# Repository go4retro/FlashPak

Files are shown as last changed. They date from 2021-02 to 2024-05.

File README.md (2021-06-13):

# FlashPak - 512kB FLASH ROM Cartridge Unit for the TANDY Color Computer 1, 2, 3, and Dragon

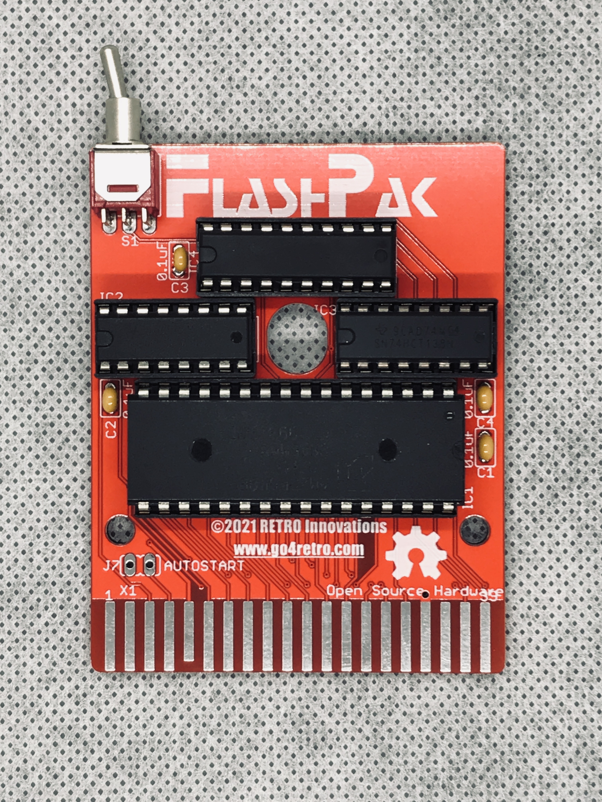
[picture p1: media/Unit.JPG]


This cartridge supports 512kB of system programmable FLASH ROM utilizing the RoboCop (Zumwalt) banking system.

## Technical Details
Banks are 16kB in size (technically, 16KiB - 256 bytes, since $ff00-$ffff is reserved for IO and vectors), which allows operation on all TANDY Color Computer models and the Dragon Data Dragon machines.  FLASH ROM appears at location $c000 in the memory map, while the banking register appears at $ff40.  The bits in the banking register are as follows:

| IO Location | Bit Location | Description |
| --- | --- | --- |
| $ff40 | 4:0 | FLASH address lines A18-A14 |
| | 7 | 1 = Programming Enabled |

The system is designed to utilize AM29F040B FLASH ROMs, but can also accommodate 16kB-512kB FLASH ROMs or EPROMs via J1-J5.  Please see schematic for more details.  If EPROMs are utilized, IC3 is not required (EPROMs cannot be system programmable)

To program please consult the AM29F040B datasheet for details, but essentially:

* set bit 7 to 1 and select bank in bank register
* via machine language, store the following values:
* store $aa in $c555
* store $55 in $c2aa
* store $a0 in $c555
* store desired value in $c000-$feff address ($fdff on Color Computer 3, I believe)

Sample stub code is available in the src/ directory.  The programming must be precise and cannot easily be performed from BASIC[1].

[1]: To simplify construction and reduce cost, programming is enabled for all of $c000-$ffff.  This includes the entire $ffxx IO region.  Unless care is taken to disable BASIC or the IRQ handlers from accessing $ffxx regions while sending the special programming sequence, the sequence will be disrupted and programming will not occur.

## Photos

Unit

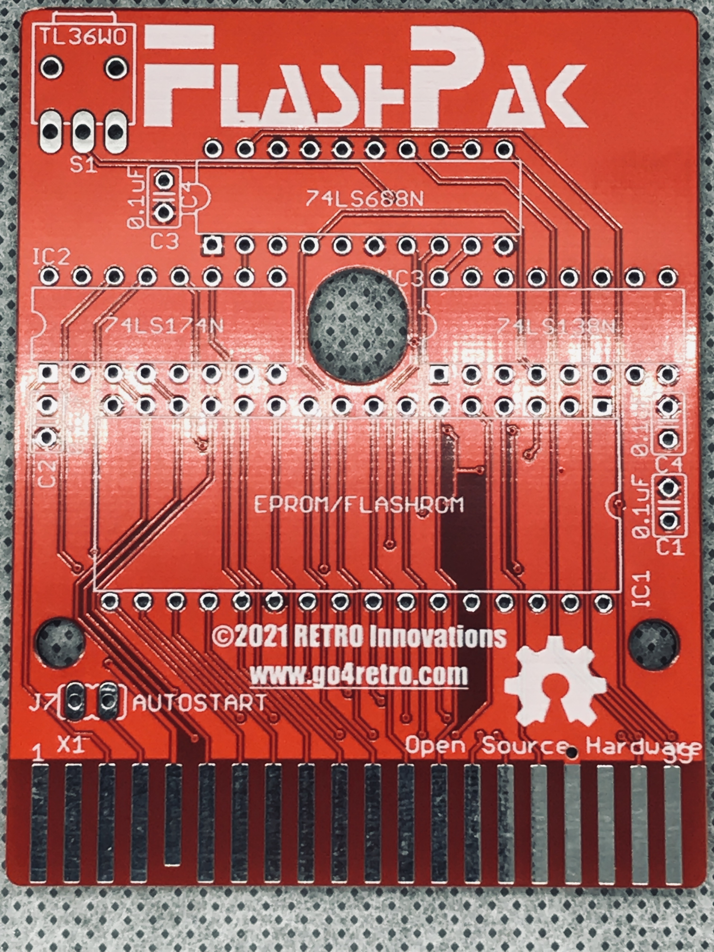
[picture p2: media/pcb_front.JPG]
pcb_front


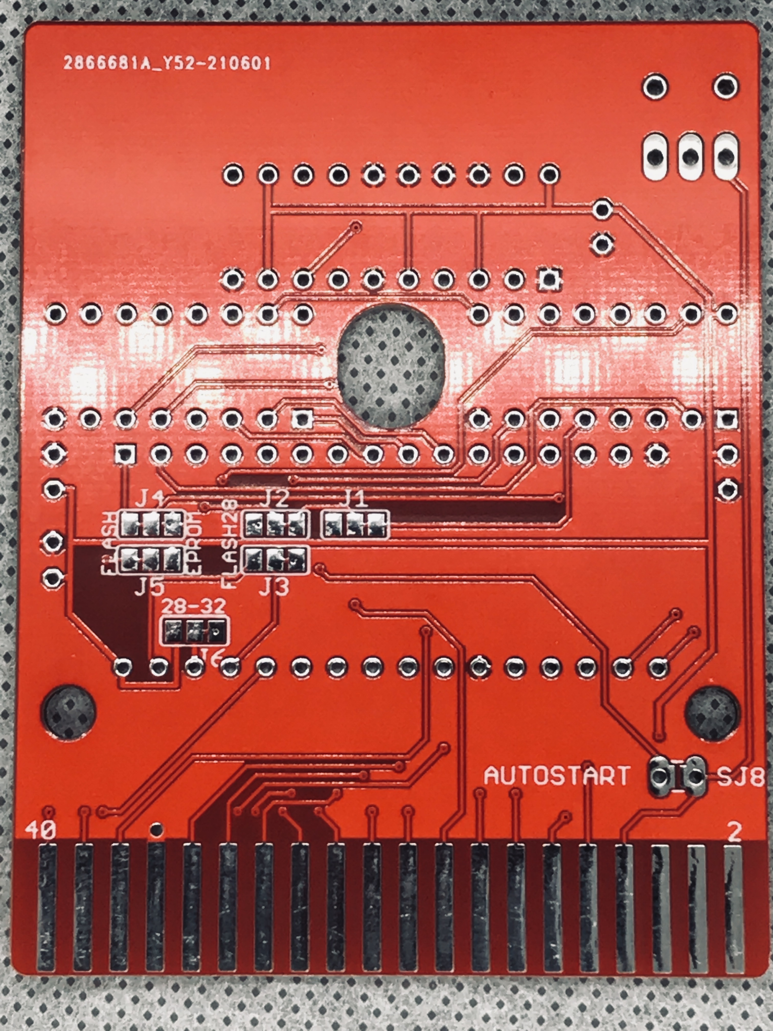
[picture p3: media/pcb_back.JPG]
pcb_back


## License
Copyright (C) 2021  RETRO Innovations

These files are free designs; you can redistribute them and/or modify
them under the terms of the Creative Commons Attribution-ShareAlike 
4.0 International License.

You should have received a copy of the license along with this
work. If not, see <http://creativecommons.org/licenses/by-sa/4.0/>.

These files are distributed in the hope that they will be useful,
but WITHOUT ANY WARRANTY; without even the implied warranty of
MERCHANTABILITY or FITNESS FOR A PARTICULAR PURPOSE.  See the
license for more details.

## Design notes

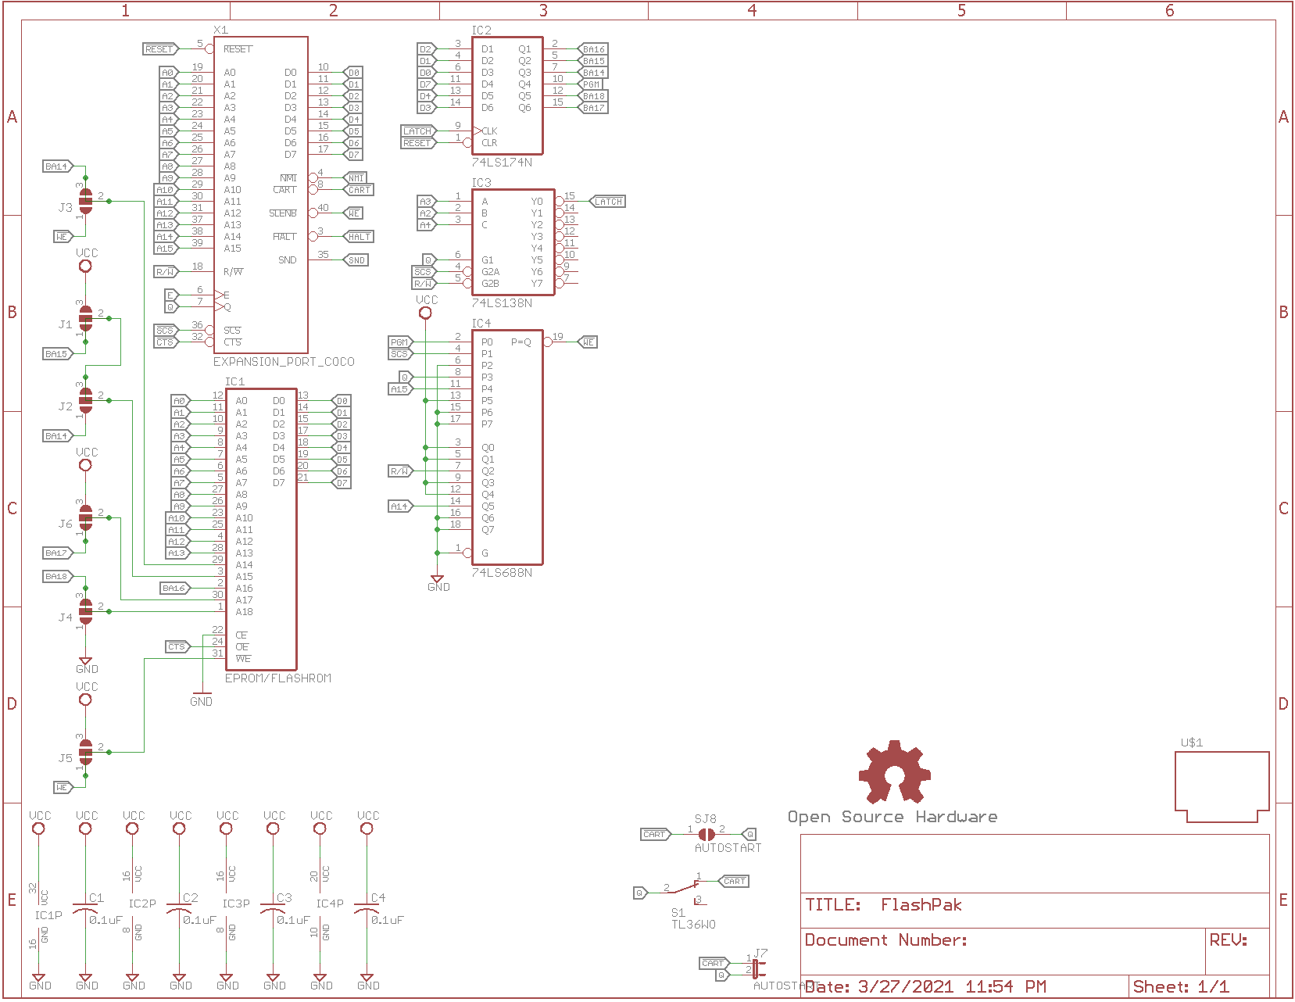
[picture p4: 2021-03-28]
pcb/FlashPak Schematic.png

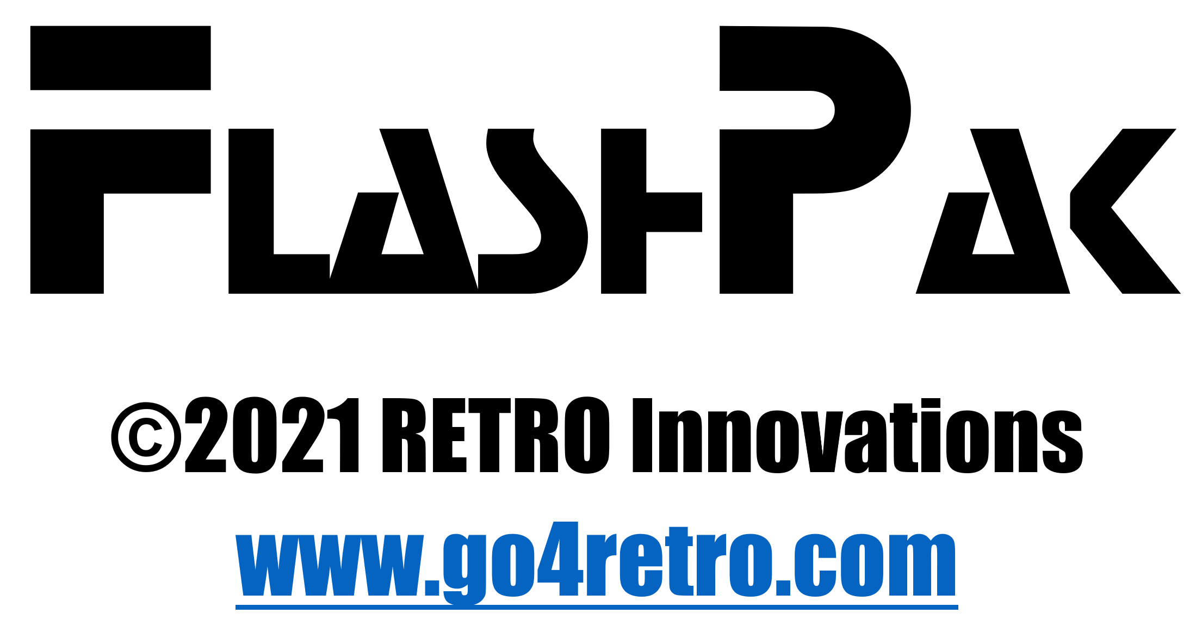
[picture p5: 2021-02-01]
doc/FlashPak Label.PNG

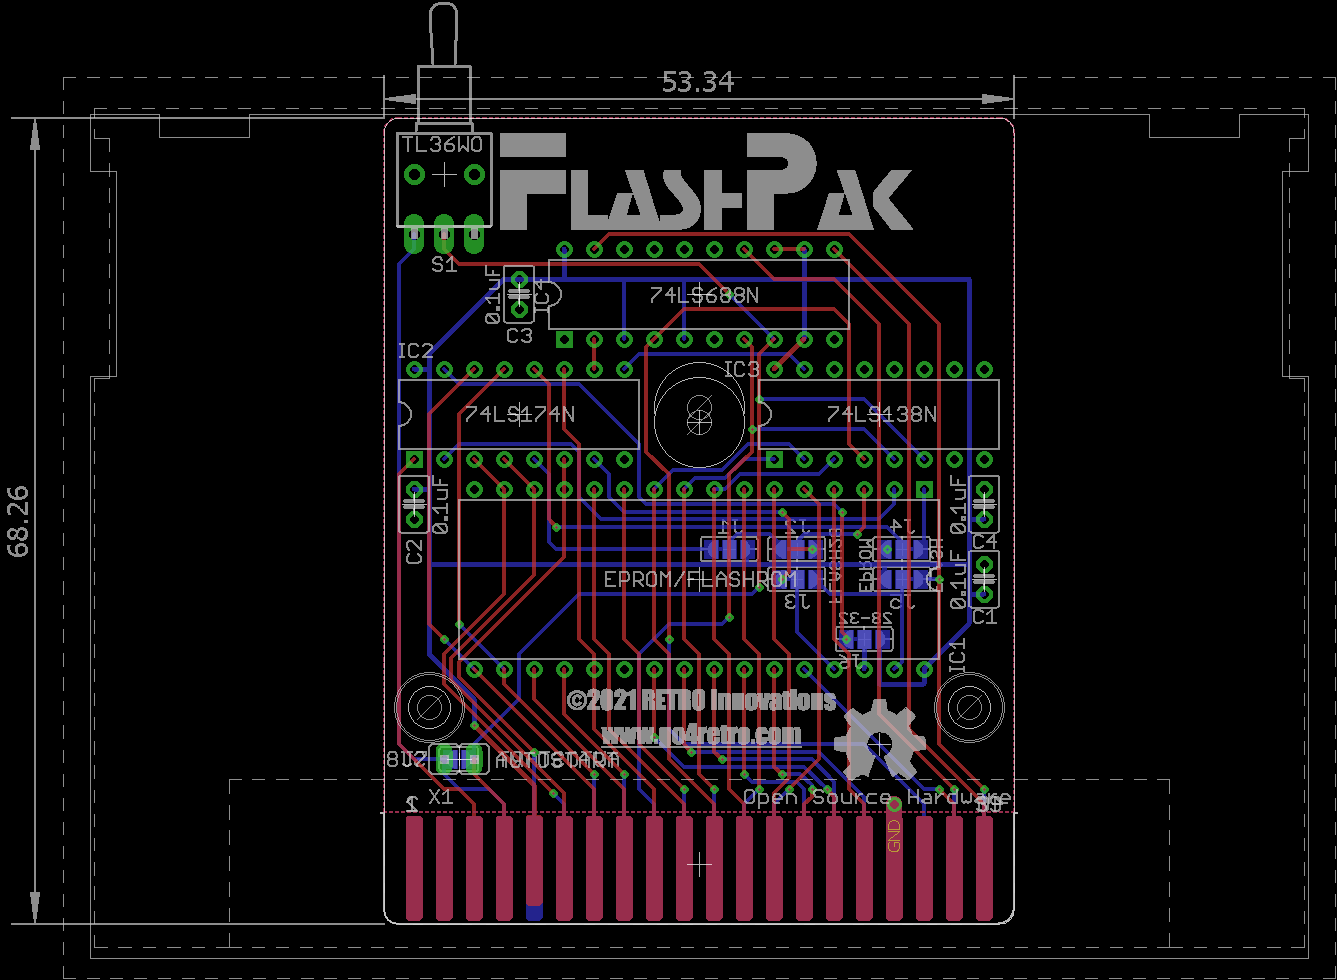
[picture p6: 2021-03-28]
pcb/FlashPak PCB.png

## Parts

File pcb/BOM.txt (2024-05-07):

Partlist

Exported from FlashPak.sch at 5/6/2024 11:41 PM

EAGLE Version 7.7.0 Copyright (c) 1988-2016 CadSoft

Assembly variant: 

Part     Value               Device              Package      Library     Sheet

C1       0.1uF               C-US025-025X050     C025-025X050 rcl         1
C2       0.1uF               C-US025-025X050     C025-025X050 rcl         1
C3       0.1uF               C-US025-025X050     C025-025X050 rcl         1
C4       0.1uF               C-US025-025X050     C025-025X050 rcl         1
IC1      EPROM/FLASHROM      SST39SF040APHR      DIL32-RP     memory-sst  1
IC2      74LS174N            74LS174N            DIL16-RP     74xx-us-jlb 1
IC3      74LS138N            74LS138N            DIL16-RP     74xx-us-jlb 1
IC4      74LS688N            74LS688N            DIL20-RP     74xx-us-jlb 1
S1       TL36WO              TL36WO              TL3XWO       switch      1
SJ8      AUTOSTART           SJ                  SJ           jumper-jlb  1

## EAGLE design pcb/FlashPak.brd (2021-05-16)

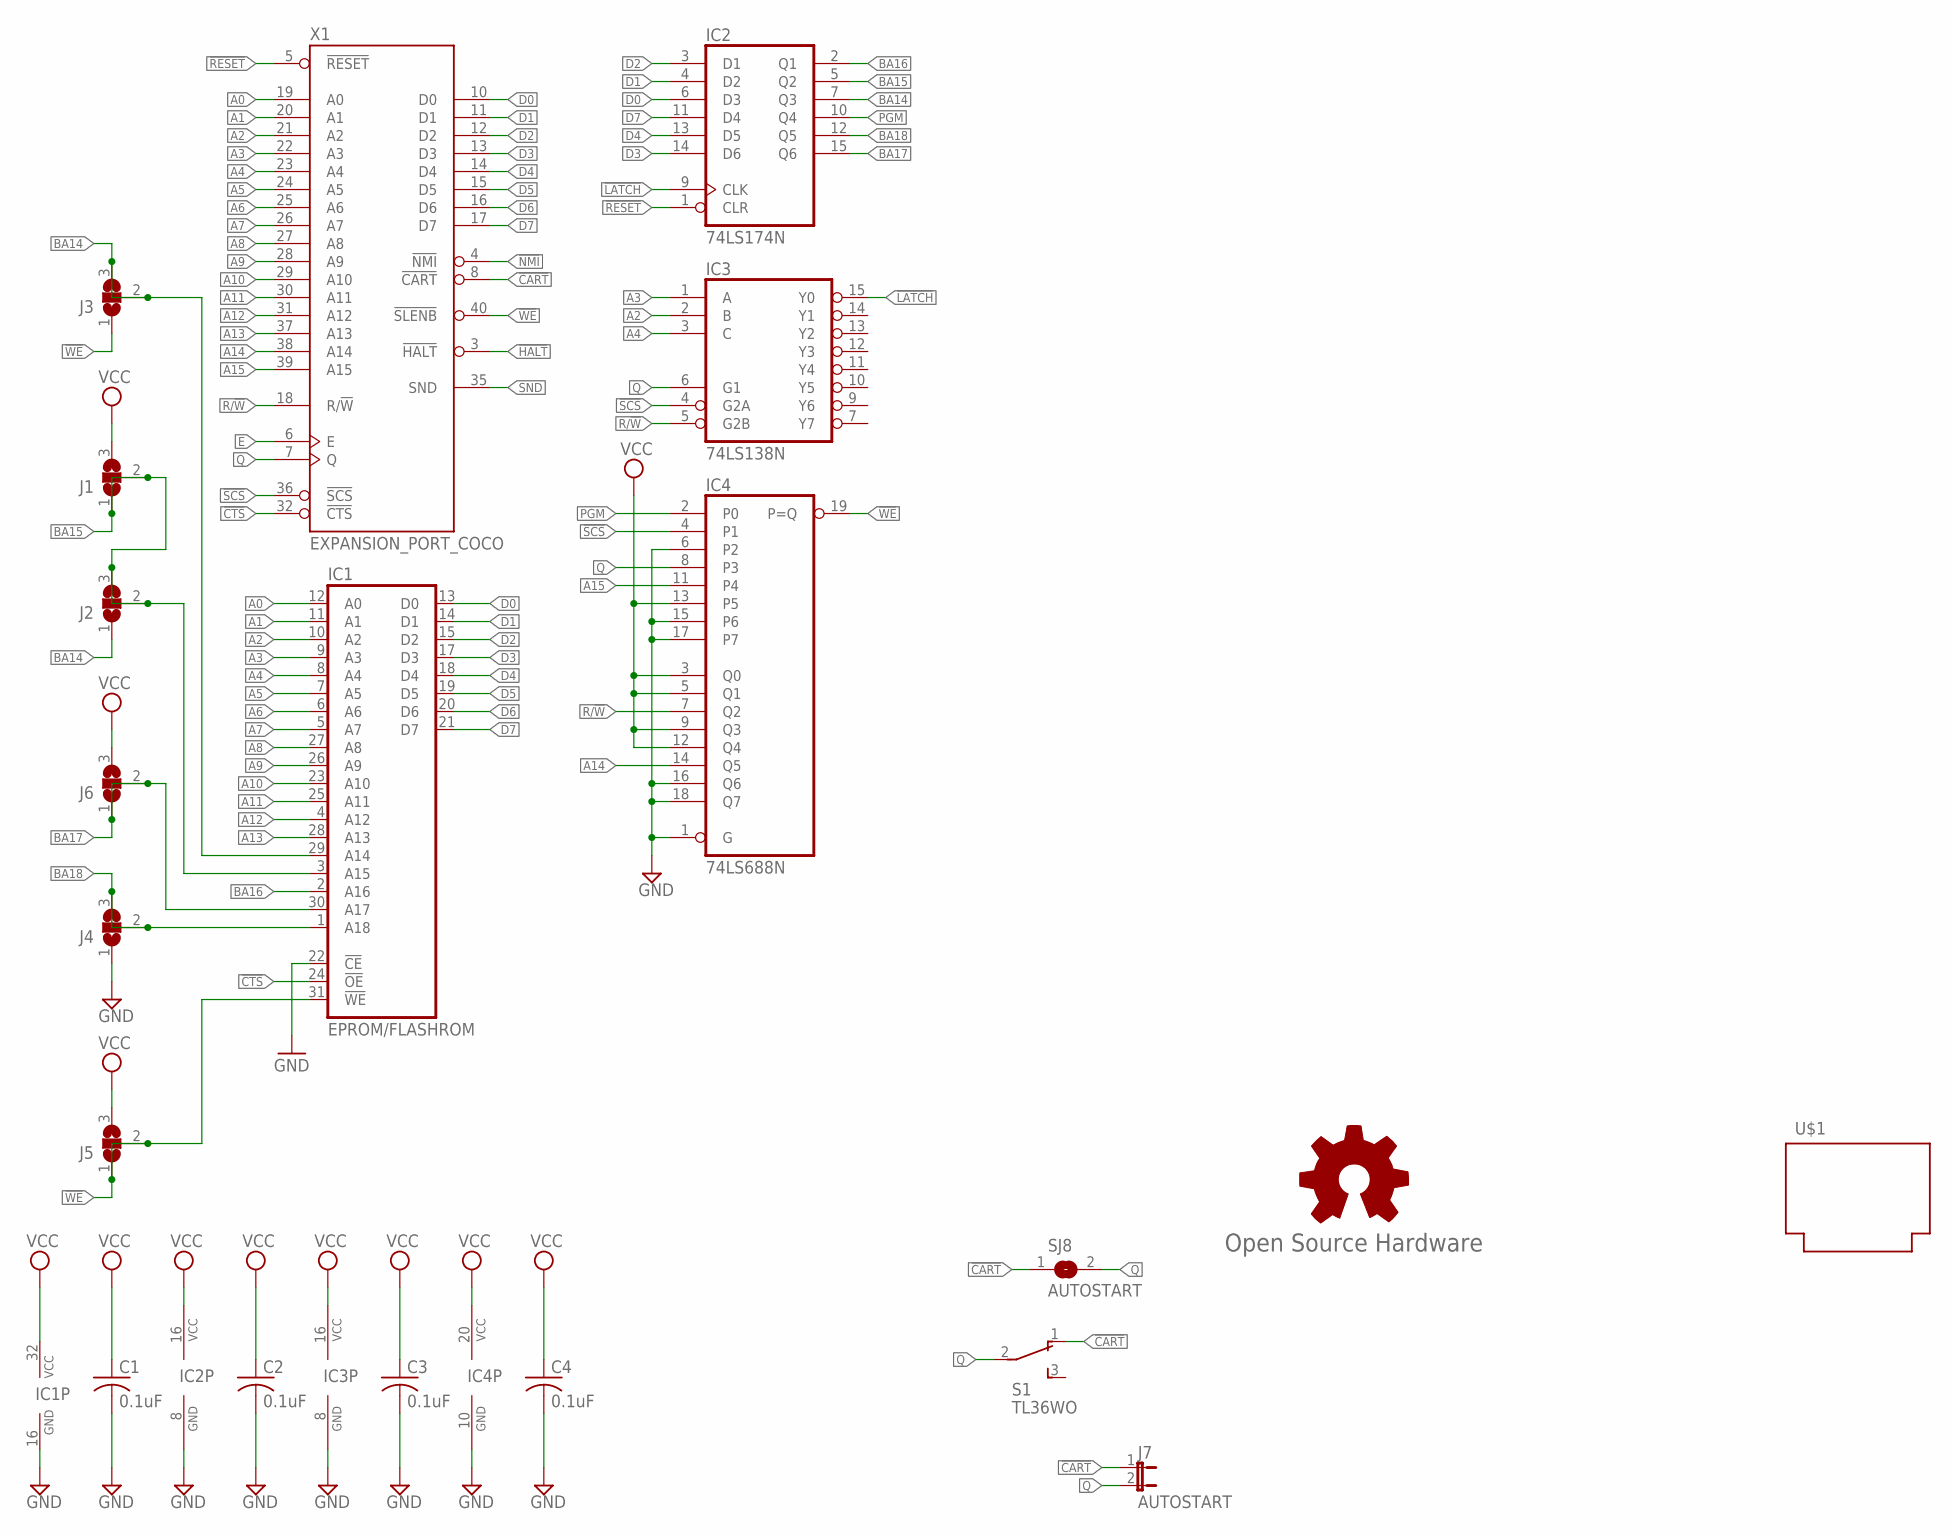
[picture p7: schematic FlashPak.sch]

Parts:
C1, C2, C3, C4: 0.1uF; C025-025X050
GOLD_ORB_SM1: Open Source Hardware; OSHW_8MM
IC1: EPROM/FLASHROM; DIL32-RP
IC2: 74LS174N; DIL16-RP
IC3: 74LS138N; DIL16-RP
IC4: 74LS688N; DIL20-RP
J1, J2, J3, J4, J5, J6: SJ2W; SJ_2
J7: AUTOSTART; JP1
S1: TL36WO; TL3XWO
SJ8: AUTOSTART; SJ
U$1: PROGRAM_PAK
X1: EXPANSION_PORT_COCO; MA20-2

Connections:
!CART: J7.1, S1.1 (O), SJ8.1, X1.8 (!CART)
!CTS: IC1.24 (!OE), X1.32 (!CTS)
!HALT: X1.3 (!HALT)
!LATCH: IC2.9 (CLK), IC3.15 (Y0)
!NMI: X1.4 (!NMI)
!RESET: IC2.1 (CLR), X1.5 (!RESET)
!SCS: IC3.4 (G2A), IC4.4 (P1), X1.36 (!SCS)
!WE: IC1.31 (!WE), IC4.19 (P=Q), J3.1, J5.1, J5.2, X1.40 (!SLENB)
+12V: X1.2 (+12V)
-12V: X1.1 (-12V)
A0: IC1.12 (A0), X1.19 (A0)
A1: IC1.11 (A1), X1.20 (A1)
A2: IC1.10 (A2), IC3.2 (B), X1.21 (A2)
A3: IC1.9 (A3), IC3.1 (A), X1.22 (A3)
A4: IC1.8 (A4), IC3.3 (C), X1.23 (A4)
A5: IC1.7 (A5), X1.24 (A5)
A6: IC1.6 (A6), X1.25 (A6)
A7: IC1.5 (A7), X1.26 (A7)
A8: IC1.27 (A8), X1.27 (A8)
A9: IC1.26 (A9), X1.28 (A9)
A10: IC1.23 (A10), X1.29 (A10)
A11: IC1.25 (A11), X1.30 (A11)
A12: IC1.4 (A12), X1.31 (A12)
A13: IC1.28 (A13), X1.37 (A13)
A14: IC4.14 (Q5), X1.38 (A14)
A15: IC4.11 (P4), X1.39 (A15)
BA14: IC1.29 (A14), IC2.7 (Q3), J2.1, J3.2, J3.3
BA15: IC1.3 (A15), IC2.5 (Q2), J1.1, J1.2, J2.2, J2.3
BA16: IC1.2 (A16), IC2.2 (Q1)
BA17: IC1.30 (A17), IC2.15 (Q6), J6.1, J6.2
BA18: IC1.1 (A18), IC2.12 (Q5), J4.2, J4.3
D0: IC1.13 (D0), IC2.6 (D3), X1.10 (D0)
D1: IC1.14 (D1), IC2.4 (D2), X1.11 (D1)
D2: IC1.15 (D2), IC2.3 (D1), X1.12 (D2)
D3: IC1.17 (D3), IC2.14 (D6), X1.13 (D3)
D4: IC1.18 (D4), IC2.13 (D5), X1.14 (D4)
D5: IC1.19 (D5), X1.15 (D5)
D6: IC1.20 (D6), X1.16 (D6)
D7: IC1.21 (D7), IC2.11 (D4), X1.17 (D7)
E: X1.6 (E)
GND: C1.2, C2.2, C3.2, C4.2, IC1.16 (GND), IC1.22 (!CE), IC2.8 (GND), IC3.8 (GND), IC4.1 (G), IC4.6 (P2), IC4.10 (GND), IC4.15 (P6), IC4.16 (Q6), IC4.17 (P7), IC4.18 (Q7), J4.1, X1.33 (GND), X1.34 (GND)
PGM: IC2.10 (Q4), IC4.2 (P0)
Q: IC3.6 (G1), IC4.8 (P3), J7.2, S1.2, SJ8.2, X1.7 (Q)
R/!W: IC3.5 (G2B), IC4.7 (Q2), X1.18 (R/!W)
SND: X1.35 (SND)
VCC: C1.1, C2.1, C3.1, C4.1, IC1.32 (VCC), IC2.16 (VCC), IC3.16 (VCC), IC4.3 (Q0), IC4.5 (Q1), IC4.9 (Q3), IC4.12 (Q4), IC4.13 (P5), IC4.20 (VCC), J1.3, J5.3, J6.3, X1.9 (VCC)

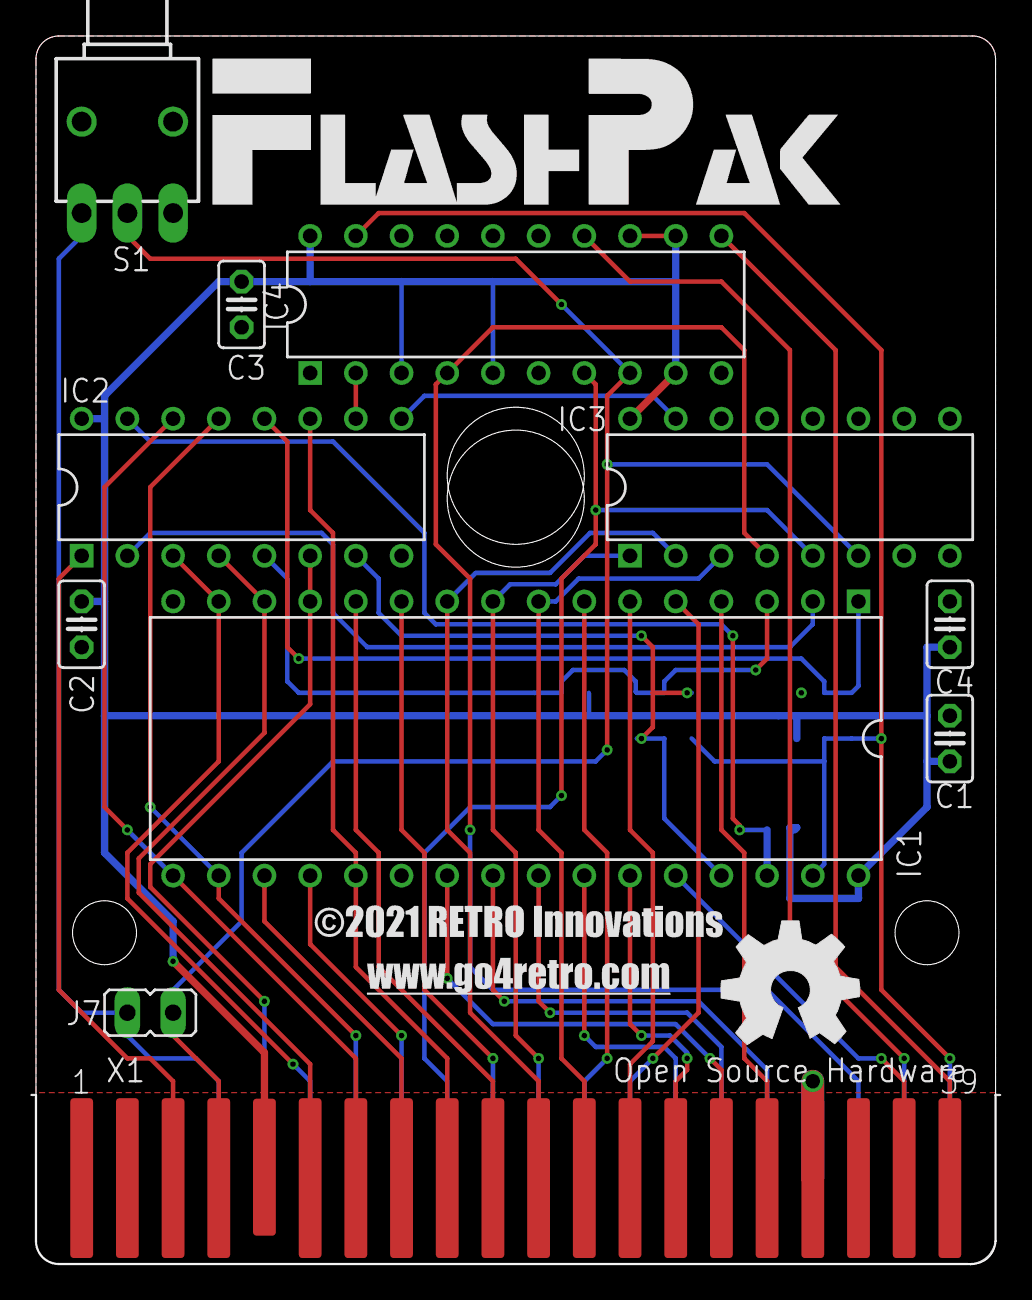
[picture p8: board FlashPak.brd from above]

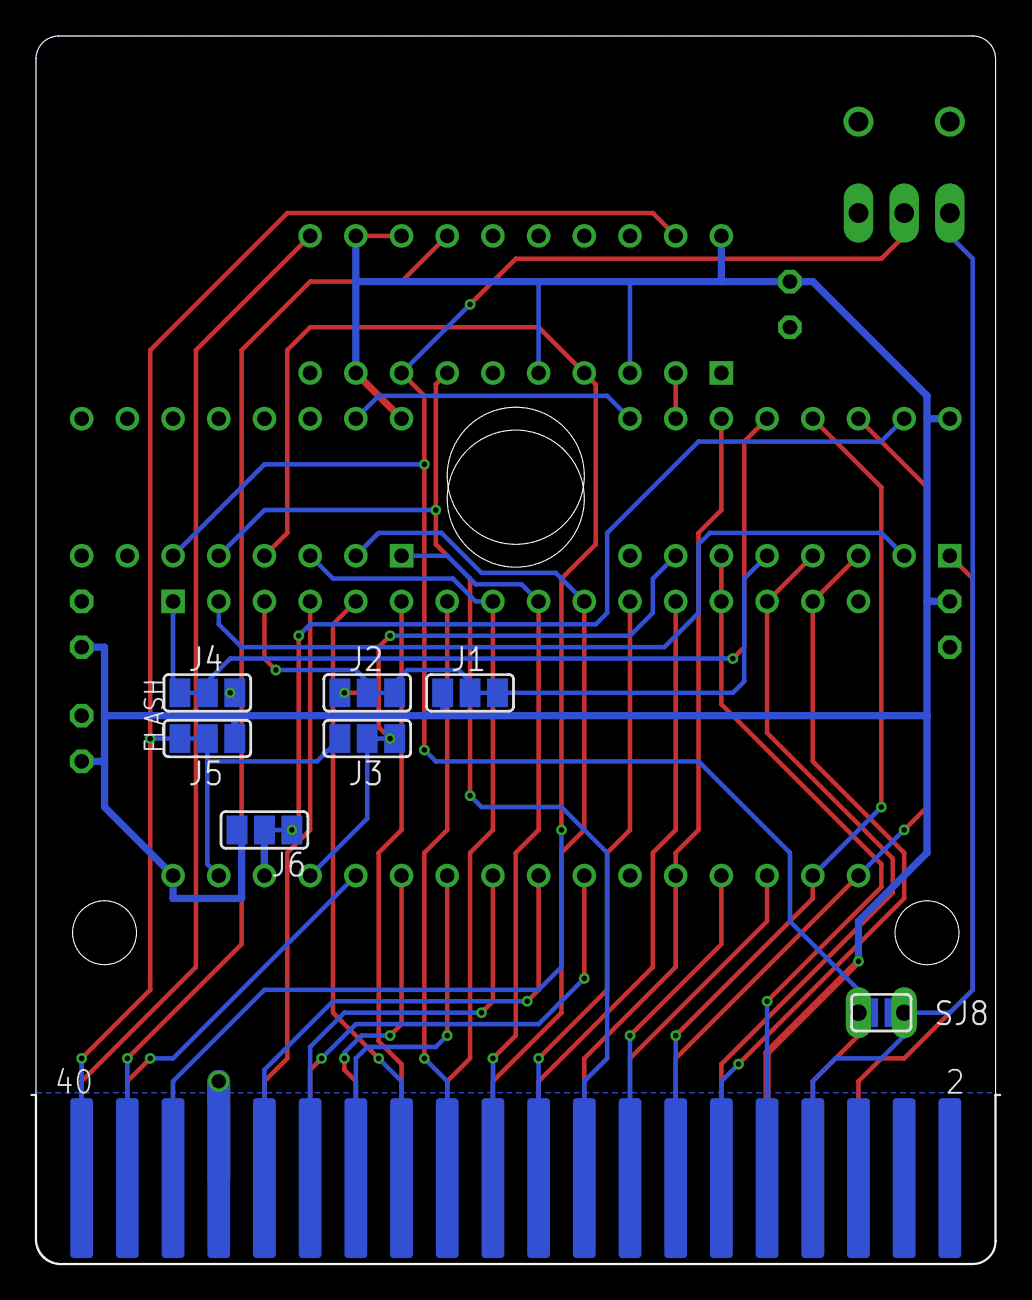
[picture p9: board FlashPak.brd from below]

Board: 2 copper layers, 53.3 x 68.3 mm, 20 parts (7 on the bottom side), 40 nets.

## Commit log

2021-01-17 Fixed issue with MPI use, added ASM, and wrote sample BASIC code
    [FlashPak.brd, FlashPak.sch]
2021-01-18 Switch to Makefile
2021-01-27 Add pic of assembled unit
2021-02-01 Added a bit of length to the cartridge design to enable easy AUTOSTART access
    [FlashPak.brd, FlashPak.sch]
2021-03-28 Fix bug where updating bank reg while in write mod causes race condition
    [FlashPak.brd, FlashPak.sch]
2021-05-16 Vcc loop removed, final Gerbers created
    [FlashPak.brd]
2024-05-07 Add BOM.txt
